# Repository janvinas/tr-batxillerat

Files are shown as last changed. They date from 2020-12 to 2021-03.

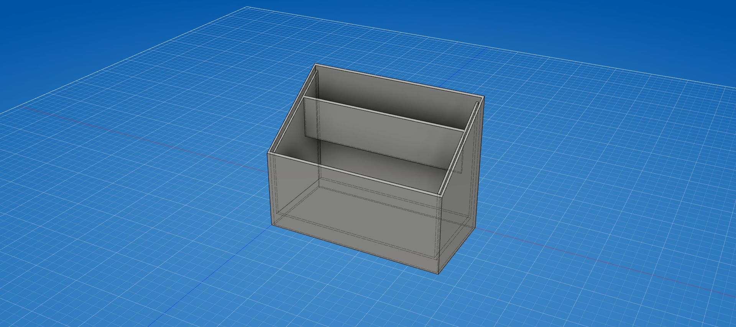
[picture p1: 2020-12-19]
imatges/exterior v4 (solid).png

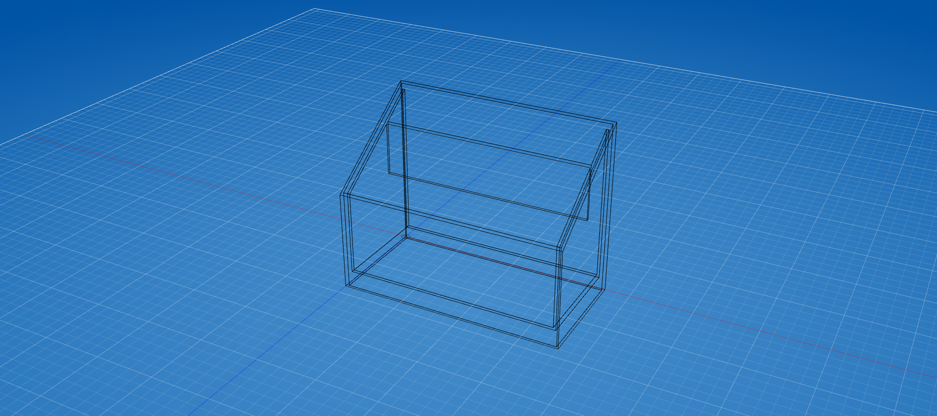
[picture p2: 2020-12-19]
imatges/exterior v4 (wireframe).png

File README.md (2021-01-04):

# Treball de Recerca de Batxillerat
__Jan Viñas Corella__

En aquest repositori trobareu el codi que he escrit pel treball de recerca. Per veure les diferents versions de cada arxiu podeu obrir l'historial.
Actualment aquest projecte no està acabat, i el codi pot contenir errors. A més, és possible que ho mogui a un altre repositori en el futur.

## Què hi trobareu
Aquí hi ha una petita explicació del contingut de cada directori, que pot ajudar a entendre l'estructura del projecte. Dins de cada directori hi ha un fitxer .ino que conté el programa.
- `3D`: dissenys 3D de la carcassa de protecció de la part exterior en diferents formats.
- `electrònica`: esquemes electrònics dels dos dispositius.
- `imatges`: imatges de diverses etapes de desenvolupament del producte.
- `partExterior`: codi pel dispositu que s'ubica a l'exterior, encarregat de recollir dades meteorològiques.
- `partExteriorV2`: actualització de la part exterior, que he volgut mantenir separada perquè no es basa en la primera versió.
- `receptor`: codi pel dispositiu que rep les dades de la part exterior i les envia a un servidor per l'emmagatzematge.

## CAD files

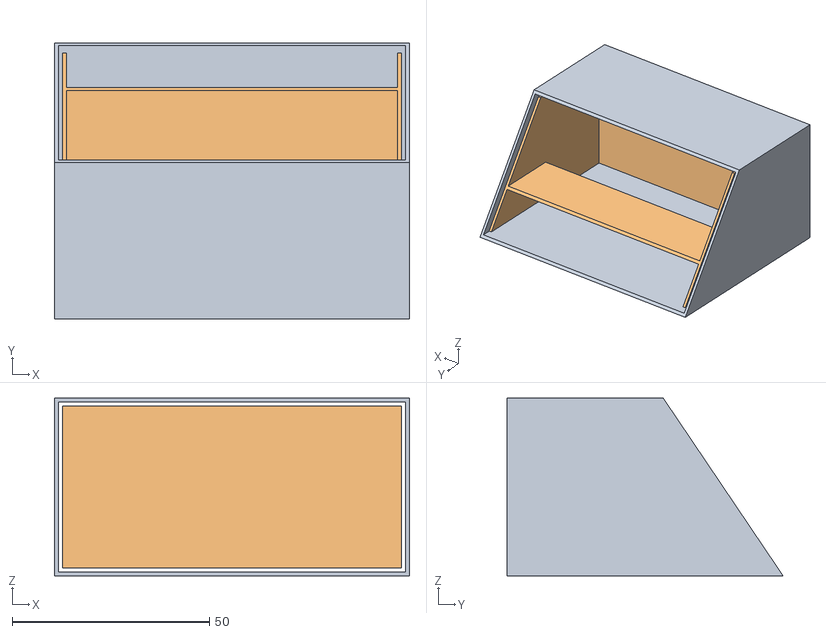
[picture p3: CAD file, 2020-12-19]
3D/exterior v4.obj
90.0 x 70.0 x 45.0

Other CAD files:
3D/exterior v4.f3d

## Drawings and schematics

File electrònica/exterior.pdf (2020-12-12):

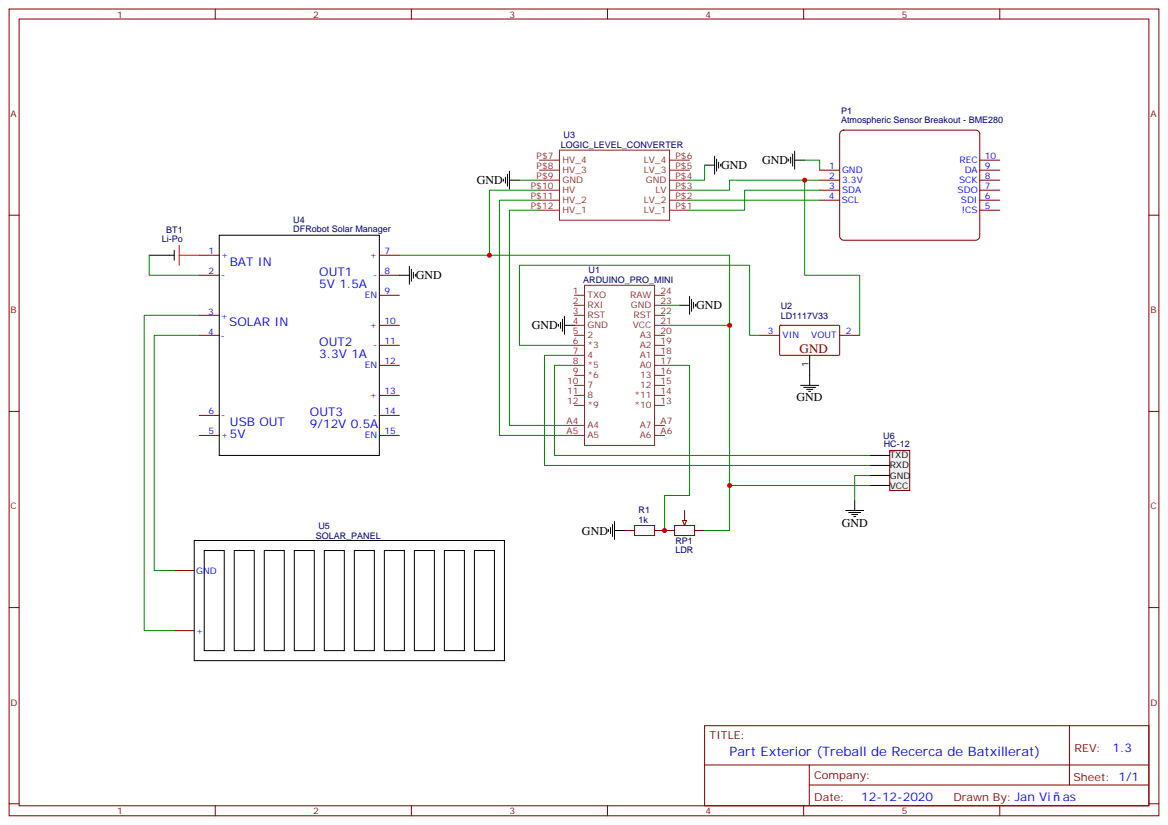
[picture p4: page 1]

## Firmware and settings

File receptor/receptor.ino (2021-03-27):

#include <ESP8266WiFi.h>
#include <ESP8266HTTPClient.h>
#include <WiFiClientSecureBearSSL.h>
#include <SoftwareSerial.h>
#include <Wire.h>
#include <SSD1306Wire.h>
#include <IRremoteESP8266.h>
#include <IRrecv.h>
#include <IRutils.h>

#define IO_KEY "***" //clau per l'API d'Adafruit IO
#define WIFI_SSID "***"    //SSID Wi-Fi
#define WIFI_PASS "***"   //contrasenya Wi-Fi

#define RX_PIN 14
#define TX_PIN 12
#define LED_PIN 2
#define IR_PIN 0

SoftwareSerial HC(RX_PIN, TX_PIN);   //crea un port sèrie virtual

SSD1306Wire display(0x3c, 5, 4);

IRrecv receiver(IR_PIN);
decode_results results;

bool sendData(String feed, String data);    //prototip de la funció que envia una dada per http
void updateDisplay(String val1, String val2, String val3, String message, byte progessBar);
void updateTime(int t);
void handleIR(long long code);

long lastReading = 0;
String temperature = "--";
String pressure = "--";
String humidity = "--";
String light = "--";
float temperatureHistory[64] = {};
int historyLocation = 0;

void setup() {

  Serial.begin(115200);   //inicialitza port sèrie de hardware
  HC.begin(2400);         //inicialitza port sèrie virtual
  receiver.enableIRIn();

  pinMode(LED_PIN, OUTPUT);     //Led d'informació connectat al pin GPIO0

  display.init();
  display.setContrast(255);
  display.flipScreenVertically();
  display.clear();
  updateDisplay("--", "--", "--", "esperant informació", 0);
  
}

void loop() {

  //la següent condició s'activara quan s'hagi rebut dades del receptor de ràdio
  if(HC.available()){

    String message = HC.readString();   //emmagatzema la informació rebuda en una variable
    Serial.print("data received: ");
    Serial.println(message);            //imprimeix la informació
    digitalWrite(LED_PIN, 1);    //curt avís lluminós sobre la rebuda de dades.
    delay(100);
    digitalWrite(LED_PIN, 0);

    temperature = message.substring(0, message.indexOf(","));    //separa la informació
    message.remove(0, temperature.length() + 1);
    pressure = message.substring(0, message.indexOf(","));
    message.remove(0, pressure.length() + 1);
    humidity = message.substring(0, message.indexOf(","));
    message.remove(0, humidity.length() + 1);
    light = message.substring(0, message.indexOf(";"));

    updateDisplay(temperature, pressure, humidity, "s'ha rebut informació", 0);
    delay(1000);

    WiFi.mode(WIFI_STA);    //defineix el mode de funcionament del Wi-Fi
    WiFi.begin(WIFI_SSID , WIFI_PASS);  //connecta a la xarxa Wi-Fi amb la informació proporcionada anteriorment.
    Serial.print("connecting to wifi  network");  //espera mentre s'estableix la connexió
    while (WiFi.status() != WL_CONNECTED) {
      delay(500);
      Serial.print(".");
    }
    Serial.println("connected");    //connexió establerta, podem continuar
    
    updateDisplay(temperature, pressure, humidity, "enviant informació", 0);
    sendData("tr.temperature", temperature);    //envia cada dada amb una petició HTTP independent
    updateDisplay(temperature, pressure, humidity, "enviant informació", 1);
    delay(100);
    sendData("tr.pressure", pressure);
    updateDisplay(temperature, pressure, humidity, "enviant informació", 2);
    delay(100);
    sendData("tr.humidity", humidity);
    updateDisplay(temperature, pressure, humidity, "enviant informació", 3);
    delay(100);
    sendData("tr.light", light);
    updateDisplay(temperature, pressure, humidity, "enviant informació", 4);
    delay(500);
    updateDisplay(temperature, pressure, humidity, "esperant informació", 0);

    temperatureHistory[historyLocation] = temperature.toFloat();
    historyLocation++;
    if(historyLocation > 64) historyLocation = 0;

    lastReading = millis();
    WiFi.disconnect(true);

  }

  if (receiver.decode(&results)) {
    serialPrintUint64(results.value, HEX);
    Serial.println("");
    handleIR(results.value);
    receiver.resume();  // Receive the next value
  }

  updateTime( (millis() - lastReading) / 1000 );
}

bool sendData(String feed, String data){
  
  std::unique_ptr<BearSSL::WiFiClientSecure>client(new BearSSL::WiFiClientSecure);    //necessari per fer una petició HTTPS
  client->setInsecure();    //la seguretat no és important aquí, així que no xifrarem la connexió
  HTTPClient http;

  http.begin(*client, "https://io.adafruit.com/api/v2/janvinas/feeds/" + feed + "/data");  //URL on s'haurà de fer la petició. Depèn del "feed" que volguem utilitzar
  http.addHeader("Content-Type", "application/x-www-form-urlencoded");  //informació sobre el contingut del cos de la transmissió.
  http.addHeader("X-AIO-Key", IO_KEY);    //autenticació, necessària per publicar les dades

  int httpResponseCode = http.POST("value=" + data);    //realitza la petició i desa el codi de resposta
  Serial.println("responseCode: " + httpResponseCode);  //imprimeix el codi de resposta
  Serial.println("response: " + http.getString());      //i la resposta
  
  if(httpResponseCode > 0){
    return true;
  }else{
    return false;
  }
}

void handleIR(long long code){
  if(code == 0xFF30CF){
    updateDisplay(temperature, pressure, humidity, "esperant informació", 0);
  }else if(code == 0xFF18E7){
    updateDisplay2();
  }
}

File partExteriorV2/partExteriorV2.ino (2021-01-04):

/*
 *  PART EXTERIOR DE L'ESTACIÓ METEOROLÒGICA
 * 
 *   Treball de Recerca de Batxillerat 2020
 * 
 */

#include <LowPower.h>
#include <SoftwareSerial.h>
#include <Wire.h>
#include <Adafruit_Sensor.h>
#include <Adafruit_BME280.h>

#define activateSerial false    //només s'imprimirà missatges a serial si això està activat

#define AT_PIN 12
#define SENSOR_PIN 2

SoftwareSerial HC (4,5);

bool debug(String s){
  if(activateSerial){
    Serial.println(s);
    return true;
  }
  return false;
}

void setup() {
  pinMode(SENSOR_PIN, OUTPUT);
  pinMode(AT_PIN, OUTPUT);
  digitalWrite(AT_PIN, HIGH);

  if(activateSerial){
    Serial.begin(4800);   //inicialitza el port sèrie
    delay(10);
  }

  HC.begin(2400);
  
}

void loop() {

  digitalWrite(SENSOR_PIN, 1);
  delay(1000);
  float temperature = 0;
  float pressure = 0;
  float humidity = 0;

  Adafruit_BME280 bme;
  if(!bme.begin()){
    debug("error initializing bme");
    temperature = 0;
    pressure = 0;
    humidity = 0;
  }else{
    temperature = bme.readTemperature();  //llegeix informació del sensor ambiental
    pressure = bme.readPressure();
    humidity = bme.readHumidity();
  }
  
  digitalWrite(SENSOR_PIN, 0);
  
  int light = analogRead(A0);                 //llegeix informació del sensor de llum
  
  String dataString =                         //converteix els valors a un objecte String
    String(temperature) + "," + 
    String(pressure) + "," + 
    String(humidity) + "," +
    String(light) + ";";
  
  debug(dataString);  

  HC.print(dataString);

  for(byte i = 0; i < 37; i++){
    LowPower.powerDown(SLEEP_8S, ADC_OFF, BOD_OFF);   //espera 298s (aprox. 5 minuts, 8 * 37) per estalviar energia
  }

  
  
}

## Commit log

2020-11-06 config.h eliminat i sistema de detecció d'errors afegit
    [receptor.ino]
2020-11-06 reescrit complet del codi
    Ho pujo com a directori separat, ja que és un programa completament diferent que no substitueix l'anterior.
    + S'ha actualitzat el sistema de telecomunicacions. Ara s'utilitza un HC-12 controlat per softwareSerial
    + Falta actualitzar els comentaris.
2020-11-11 canvi a llibreria http
    Ara s'utilitza la llibreria HTTP per pujar les dades. He tret completament la llibreria Adafruit IO perquè al cap d'unes hores entrava en un bucle infinit i es penjava el programa.
2020-11-13 s'ha afegit comentaris de codi
2020-11-15 reorganització del codi per facilitar la comprensió
2020-11-15 afegir condició a la funció sendData
    per complir amb la descripció del treball, ara retorna 1 si la petició HTTP és correcte, 0 si no
    [receptor.ino]
2020-11-18 nou pinout pel canvi de placa
    a més ara el pinout està definit al principi i no programat directament
2020-11-18 afegit suport per mostrar dades a OLED
    La funció updateDisplay imprimeix les dades a la pantalla.
2020-11-19 petites modificacions visuals
    - marc il·luminat
    - barra de progrés
2020-12-06 canviar temps d'espera enviant dades
    de 24 segons a 296 segons (aprox 5 minuts)
2020-12-07 canvi en el funcionament de la connexió wi-fi
    Possible gràcies a l'augment de temps entre lectures. Ara es connecta a la xarxa només quan es volen enviar dades, i no manté la connexió sempre activa.
2020-12-10 incloure temps des de l'última lectura a la pantalla
2020-12-12 solució d'un problema amb la informació de connexió
    [receptor.ino]
2020-12-19 imatges i models 3D
    [exterior v4.f3d, exterior v4.obj]
2021-01-04 canvi de llicència
